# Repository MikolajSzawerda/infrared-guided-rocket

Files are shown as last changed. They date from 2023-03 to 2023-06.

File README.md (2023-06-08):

Mikołaj Szawerda <br/>
Dawid Kaszyński

# Projekt SKPS - Termiczny układ naprowadzania rakiety

## Założenia projektu

Projekt ma za zadanie symulować termiczny układ naprowadzania rakiety poprzez zczytywanie danych z kamery termowizyjnej i odpowiednie sterowanie dwoma serwomechanizmami w taki sposób, żeby nakierowywać w najcieplsze miejsce w obrazie. Ponadto system powinien wizualizować w czasie rzeczywistym przetwarzany obraz oraz wyświetlać wybrany cel.

## Wykonanie - zdjęcia

### Urządzenie i podłączone serwomechanizmy oraz kamera

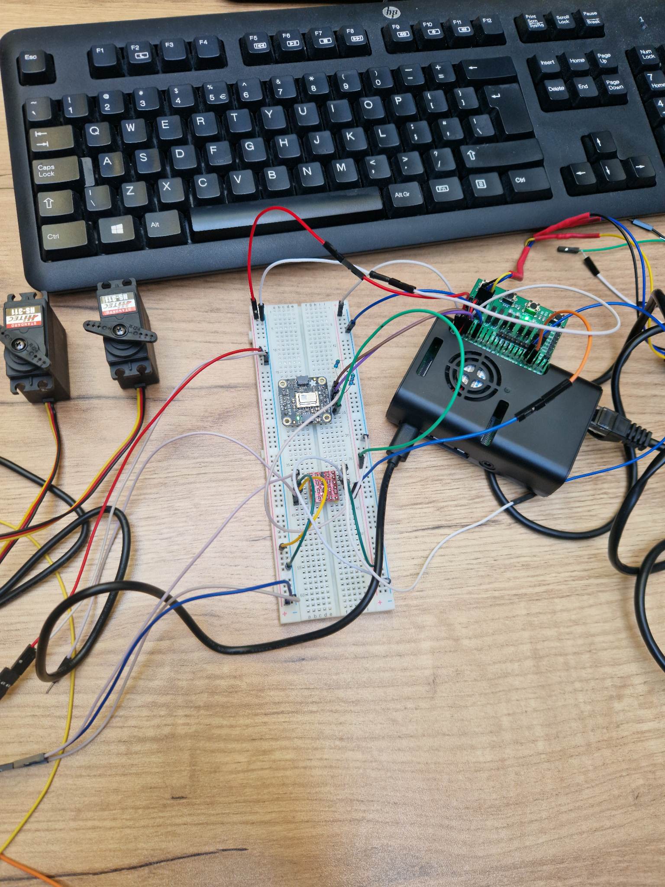
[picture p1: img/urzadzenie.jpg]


### Urządzenie wraz z widoczną wizualizacją i najcieplejszym punktem (czarna kropka na mapie ciepła)

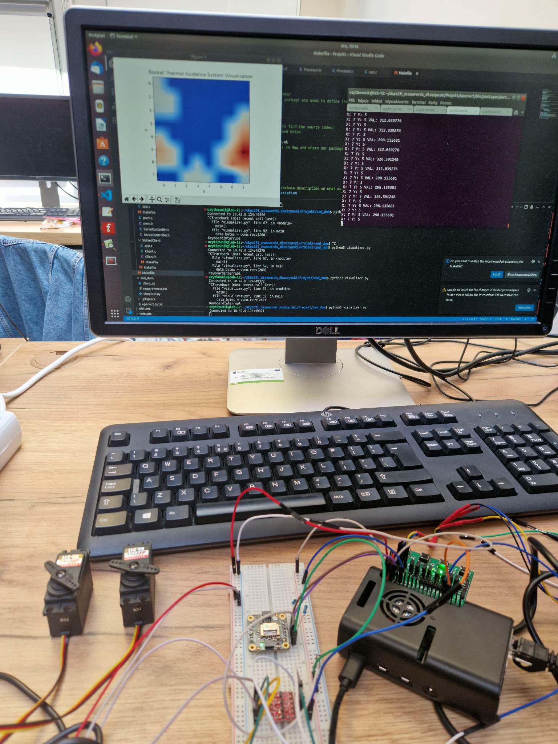
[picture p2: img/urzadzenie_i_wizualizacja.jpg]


## Wykonanie - płytka

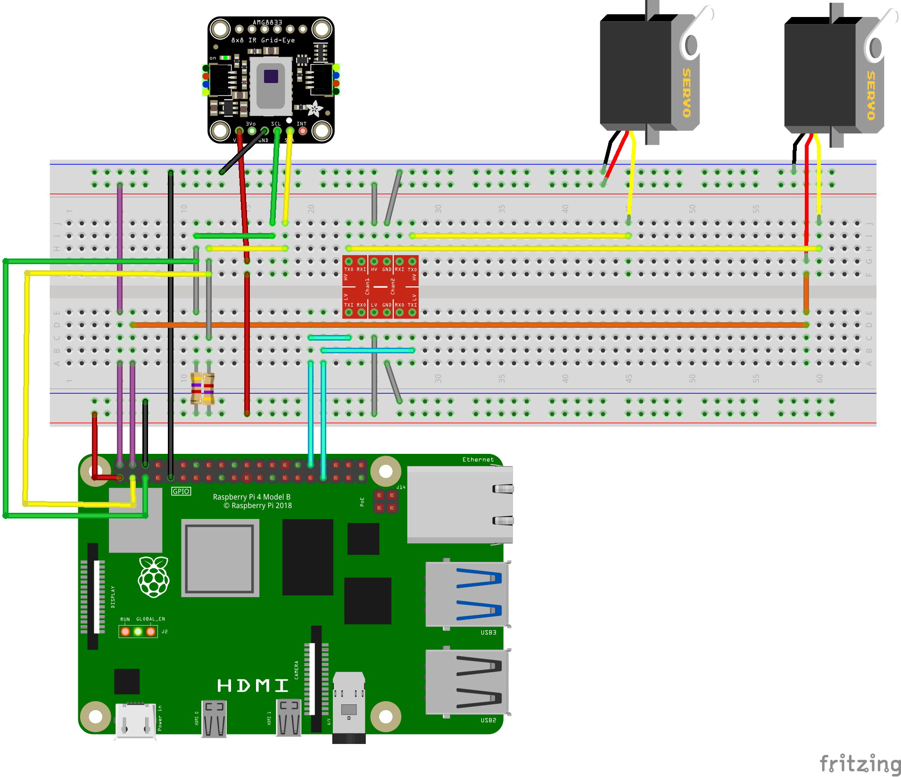
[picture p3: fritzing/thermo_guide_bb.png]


- kamera z racji komunikacji po I2C jest podłączona wraz z pull up resistorami do lini SCL i SDA
- servomechanizmy z racji wymaganego sterovania 5V są podłączone do RPI poprzez konwerter poziomów logicznych z 3.3V na 5V

## Wizualizacja

Wizualizacja w czasie rzeczywistym została zrealizowana przy pomocy połączenia RPi4 z hostem poprzez socket oraz z użyciem biblioteki matplotlib, która umożliwa wyświetlenie mapy ciepła 8x8 z włączoną interpolacją i odpowiednią kolorystyką.

Dane wysyłąne z płytki poprzez sockety to bufor 65-bajtowy, z czego pierwsze 64 bajty to dane odczytane z kamery termowizyjnej, a ostatni bajt to połozenie najciepleszego punktu, który w wizualizacji jest reprezentowany przez czarną kropkę.

## Algorytm wyszukiwania najcieplejszego punktu

Pierwszym, najprostszym pomysłem na realizację algorytmu wyszukiwania najcieplejszego punktu było zwykłe wyszukiwanie najcieplszego pixela odczytanego z kamery. Dawało to jednak złe rezultaty, ze względu na bardzo dużą oscylację odczytów i brak możliwości skupienia się na konkretnym punkcie, gdy w zasięgu kamery pojawiały się inne o zbliżonej temperaturze.

Z tego względu zdecydowaliśmy się na rozwiązanie polęgające na iteracji po całym obrazie 8x8 macierzą 3x3 i uwzględnianie średniej ważonej temperatury z całego mniejszego obszaru. Ponadto, parametrem algorytmu jest najcieplejszy punkt z poprzedniego odczytu, który powoduje, że w przypadku występowania dwóch równie ciepłych punktów w obrazie z kamery, algorytm preferuje wybór tego, który był wybrany poprzednio - umożliwia to skupienie się na konkretnym punkcie i redukuje oscylację. Co iterację wartość poprzedniego najcieplejszego punktu jest delikatnie zmniejszana poprzez mnożenie przez pewien współczynnik, aby wykluczyć zapamiętywanie punktów, które nie istnieją już w nowym odczycie z kamery.

Dodatkowym usprawnieniem jest także progowanie - odcianie temperatury do przedziału [a, b], które powoduje, że obraz jest mniej rozmyty i można lepiej rozróżnić ciepłe obszary.

## Aplikacja na RPI

Aplikacja uruchomiona na RPI została podzielona na moduły, znajdujące się w folderze `thermo_guide/src`

### SocketClient
- implementacja klienta komunikującego się po TCP socketami. Klient umożliwia przesłanie przetwarzanych przez niego danych(obrazu z kamery) i końcowego rezultatu algorytmu - piksela na który zostają nastawione serwa(indeks w buforze z obrazem)
- w folderze z kodem znajduje się również aplikacja testująca samego klienta - generuje sztuczny obraz(orbitujący punkt) wraz z losowym szumem i przesyła go po socketcie

### ServoController
- moduł z funkcjami umożliwiającymi sterowanie serwami
- funkcje korzystają z fragmentu biblioteki `C-periphery` w celu wysterowania odpowiedniego sygnału PWM.
- funkcja `init_servo` rozpoczyna komunikację programu z chipem pwm i ustawia częstotliwość pracy PWM
- ponieważ nie posiadaliśmy informacji o typie serva przed laboratoriami przygotowaliśmy funkcję sterujące servem w trybie ciągłym i wychyleniowym
- `set_servo_rot_direction` ustawia wypełnienie serva, decydując o jego wychyleniu
- `step_set_servo_pixel` mapuje wymagane wychylenie do wypełnienia z przedziału `[MIN_ANGLE, MAX_ANGLE]`
- folder zawiera również aplikację testową do zbadania minimalnego i maksymalnego wypełnienia dającego zmianę wychylynie

### ImageProcessor
- moduł z implementacją algorytmu znajdowania najcieplejszego punktu
- folder zawiera również aplikację do testowania funkcjonalności

### Camera
- moduł do pobierania danych z kamery wykorzystując I2C
- pakiet jest fuzją oficjalnej biblioteki do kamery w C i części biblioteki `C-periphery` do obsługi protokołu I2C.
- folder zawiera aplikację testującą odczytywane dane

### App
- główna aplikacja wykorzystująca zaimplementowane funkcjonalności
- przepływ aplikacji:
    - inicjacja połączenia z serverm na hoscie
    - inicjacja urządzenia I2C i sygnału PWM dla serv
    - w pętli:
        - odczyt z kamery
        - przetworzenie obrazu i odebranie najcieplejszego punkty
        - wysterowanie serv i wysyłka pakietu do servera
        - odczekanie w celu równomiernego próbkowania obrazu

### Pozostałe
- w celu ułatwienia i przyspieszenia pracy z OpenWRT w folderze `scripts/` znajdują shell'owe skrypty

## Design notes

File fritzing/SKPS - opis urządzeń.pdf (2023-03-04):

# Obsługa interfejsów komunikacyjnych na RPi

Dokument przygotowany dla przedmiotu SKPS Autor: Dawid Seredyński

i2c

Należy podłączyć do linii SDA i SCL rezystory o wartości około 4,7kΩ (pull-up).

Trzeba dodać do config.txt na partycji boot:
dtoverlay=i2c1

i2c1 (przez GPIO 2 i 3) jest wyprowadzone na adapterze na dedykowanym złączu.

W OpenWRT należy doinstalować:
kmod-i2c-bcm2835

Podłączone urządzenie można wykryć za pomocą polecenia: i2cdetect -y 1

## 1-wire

Włączenie 1-wire interface w RPi (przez dtoverlay) jest opisane m.in. na stronie: https://www.raspberrypi-spy.co.uk/2018/02/enable-1-wire-interface-raspberry-pi (uwaga: dla urządzenia DHT11, interfejs włącza się w inny sposób)

# Opis wybranych urządzeń

## VL53L0 - laserowy czujnik odległości (time of flight)

Interfejs: i2c
Adres: 0x29
Możliwości: precyzyjny pomiar odległości w zakresie 2m.

Dokumentacja jest dostępna pod adresem: https://download.kamami.pl/p570404-VL53L0X%20Datasheet.pdf

Urządzenie wymaga użycia bardzo złożonego API.
Uruchomienie na RPi wymaga skorzystania z oryginalnego API od ST, które jest dostępne pod adresem:
https://www.st.com/en/embedded-software/stsw-img005.html

Należy ściągnąć STSW-IMG005. API jest bezpłatne, ale wymagane jest podanie i potwierdzenie adresu e-mail.

Następnie można skorzystać z biblioteki dla RPi: https://github.com/cassou/VL53L0X_rasp

Plików źródłowych w API i w bibliotece nie trzeba zmieniać, a jedyna trudność polega na stworzeniu pakietu dla OpenWRT, w którym będą pliki źródłowe z API i biblioteki.

## LCD-02351 (2x16 znaków) + konwerter i2c

Interfejs: i2c
Możliwości: wyświetlanie tekstu w dwóch liniach po 16 znaków.

Konwerter i2c na bazie PCF8574.

## DFR0316 - 18-bitowy, 4-kanałowy konwerter analogowo -cyfrowy

Interfejs: i2c
Możliwości: konwersja analogowego sygnały (poziom napięcia) na cyfrową wartość 18-bitową, na 4 kanałach.

Moduł na bazie układu MCP3424 (dokumentacja jest na Moodle).

## AMG8833 - kamera termowizyjna 8x8

Interfejs: i2c
Adres: 0x69
Możliwości: Uzyskanie obrazu termowizyjnego 8x8 dla zakresu temperatur 0-80 st. C.

Dokumentacja jest dostępna na stronie kursu na Moodle.

Prosta obsługa. Można skorzystać z fragmentów kodu biblioteki dla Arduino: https://github.com/adafruit/Adafruit_AMG88xx

## DHT11 - czujnik temperatury i wilgotności

Interfejs: 1-wire
Możliwości: pomiar temperatury i wilgotności

Można uruchomić zgodnie z opisem dostępnym pod adresem: https://krystiankozak.pl/index.php/openwrt-gpio
Sterownik na RPi dla DHT11 nie działa jednak najlepiej, ale możliwe jest dokonanie odczytów.

## Jednostka inercyjna

Interfejs: i2c, SPI
Możliwości: pomiar przyspieszenia w 3 osiach, prędkości obrotowej w 3 osiach. Dodatkowo, w MPU-9250 jest także pomiar pola magnetycznego w 3 osiach.

Dostępne są dwa rodzaje jednostki inercyjnej:
- Grove - IMU 9DOF v2.0 - 3-osiowy akcelerometr, żyroskop i magnetometr I2C/SPI z układem MPU-9250. Datasheet i mapa rejestrów są udostępnione na Moodle.
- MPU-6050 3-osiowy akcelerometr i żyroskop I2C - moduł DFRobot. Datasheet i mapa rejestrów są udostępnione na Moodle.

## Moduł radiowy nRF24L01+ 2,4GHz - transceiver THT

Interfejs: SPI
Możliwości: Posiada wbudowaną antenę oraz sprzętowe kolejki FIFO. Maks. zasięg do 100m

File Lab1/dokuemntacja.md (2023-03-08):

# Lab1
## Dawid Kaszyński Mikołaj Szawerda

### Uruchomienie RPi

Do terminala UART podłączyliśmy się wykonując komendę `tio /dev/ttyUSB01`

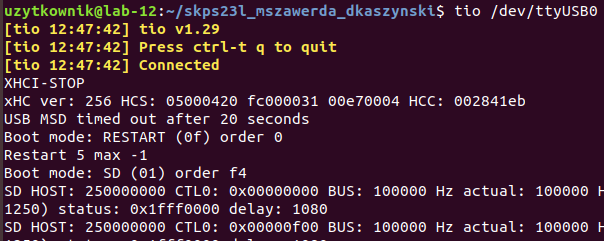
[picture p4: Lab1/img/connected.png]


Po uruchomieniu zasialania na RPi został uruchomiony system ratunkowy, zalogowaliśmy się na niego z loginem root, a następnie wykonaliśmy polecenie `udhcp`, by został przyznany adres IP

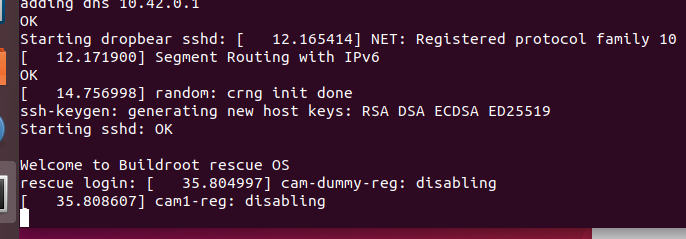
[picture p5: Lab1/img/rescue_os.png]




Sprawdzenie utworzenia podsieci między hostem a RPi.

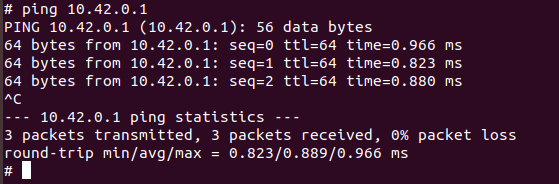
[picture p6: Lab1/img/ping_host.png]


### Kopiowanie plików

#### Test

W celu przetestowania przesyłania plików utworzyliśmy serwer http przy pomocy polecenia `python3 -m http.server`, następnie na hoscie utworzyliśmy plik testowy `foobar`, umieściliśmy go na serwerze, i na RPi pobraliśmy go korzystając z komendy `wget http://10.42.0.1:8000/foobar`



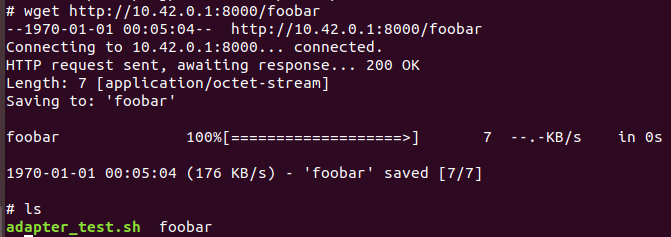
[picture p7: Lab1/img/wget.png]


### Kompilacja obrazu Linuxa

- po rozpakowaniu archiwum z Buildroota, wykorzystaliśmy predefiniowaną konfigurację domyślną dla RBi4 oraz uruchomiliśmy menu konfiguracji
```
make raspberrypi464defconfig
make menuconfig
```

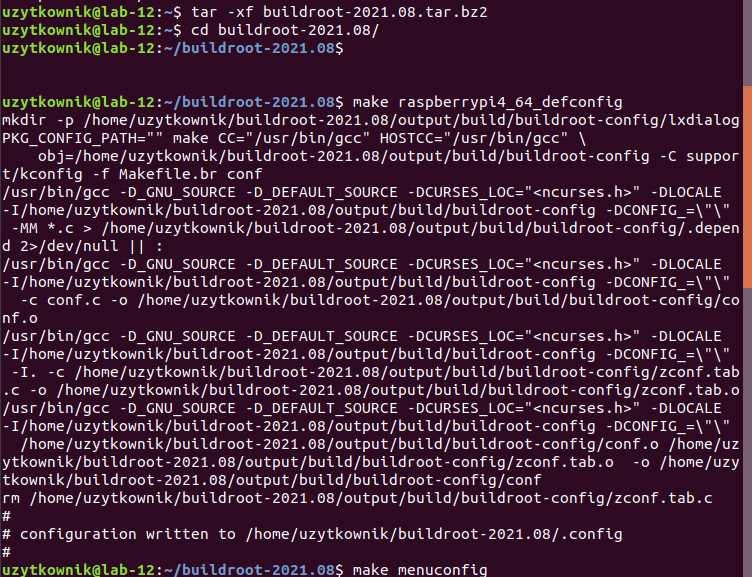
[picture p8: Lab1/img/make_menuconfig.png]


#### Wersja initramfs

Kroki:
- w meny wybranie `Toolchain --> Toolchain type: External toolchain`
- w filesystem images: zaznaczenie cpio, opcji initramfs i wyłączenie ext2/3/4, włączenie kompresji obrazu: gzip
- zapis ustawień w `.config` i urochomienie kompilacji `make`
- zamontowaliśmy partycję 1 w /mnt przy pomocy `mount /dev/mmcblk0p1 /mnt`
- skompilowany obraz `Image` pod nazwą `kernel8.img`, linię poleceń `cmdline.txt` z katologu `rpi-firmware`  i drzewo urządzeń `bcm2711-rpi-4-b.dtb` pobraliśmy z poziomu systemu ratunkwoego do katologu `/user`
- zrestartowaliśmy RBi4 `reboot` z wciśniętym przyciskiem `sw4`

#### Wersja bez initramfs

Kroki:
- usuneliśmy poprzedni obraz systemy `make linux-dirclean`
- z poprzedniej konifguracji pozostawiliśmy włączony External toolchain, oraz kompresję obrazu w Kernel
- w filesystem images: wyłączyliśmy initramfs, włączyliśmy ext2/3/4
- `make`



- następnie po uruchomieniu systemu dodaliśmy plik `test` i wykonaliśmy `reboot` systemu, po uruchomieniu plik dalej był w systemie plików

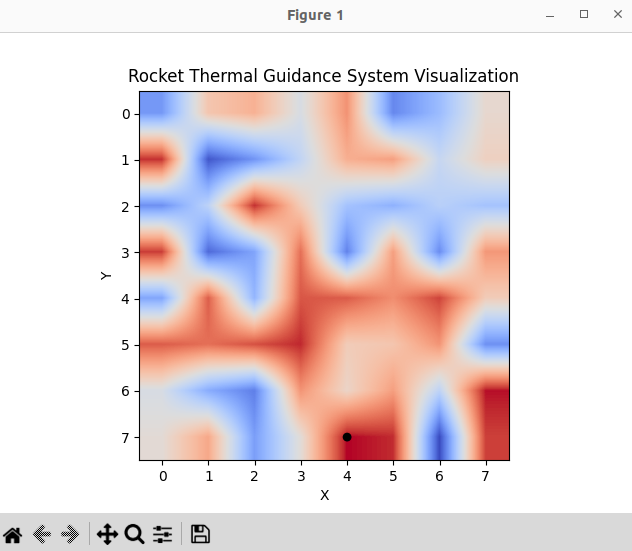
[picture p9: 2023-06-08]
img/visualization.png

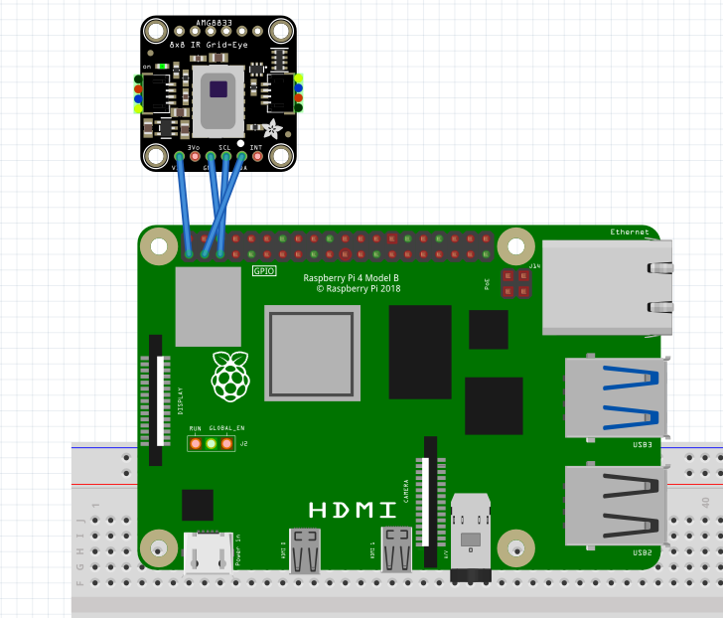
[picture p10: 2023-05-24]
schemat_termo.png

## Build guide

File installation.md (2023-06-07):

## Install OpenWRT

```shell
wget -O openwrt.tar.xz https://downloads.openwrt.org/releases/21.02.1/targets/bcm27xx/bcm2711/openwrt-sdk-21.02.1-bcm27xx-bcm2711_gcc-8.4.0_musl.Linux-x86_64.tar.xz
tar -xf openwrt.tar.xz
```

## Make link

```shell
ln -s ../../../thermo_guide thermo_guide 
```

## Preconfig openwrt

### Feeds.conf.default
```
src-link thermo_guide package/thermo_guide/src
```

### Config

```shell
scripts/feeds update -a
scripts/feeds install -p thermo_guide -a 
make menuconfig
```

Global Build Settings wyłaczyć opcje:
Select all target specific packages by default
Select all kernel module packages by default
Select all userspace packages by default
Cryptographically sign package lists

Advanced configuration options wskazane jest wyłaczenie opcji
Automatic removal of build directories

Dodać pakiet w do budowania

### Budowanie

```shell
make package/thermo_guide/compile -j4
```

```shell
make package/thermo_guide/compile -j1 V=s
```

## Na openwrt

```shell
/etc/init.d/firewall stop
```

### config.txt
```
dtoverlay=pwm-2chan,pin=12,func=4,pin2=13,func2=4
dtoverlay=i2c1
```

### Install

```shell
kmod-i2c-bcm2835
kmod-pwm-bcm2835
```

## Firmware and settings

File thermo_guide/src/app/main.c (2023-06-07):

#include <stdio.h>
#include <unistd.h>
#include <stdlib.h>
#include <string.h>
#include "../Camera/Camera.h"
#include "../SocketClient/Client.h"
#include "../ServoController/ServoController.h"
#include "../ImageProcessor/Processor.h"
#define BUFFER_SIZE 64
#define SERVER_IP "10.42.0.1"
#define SERVER_PORT 6969

double t = 0;

void print_buffer(float* buffer);

int main(){
    int sockfd = init_server_connection(SERVER_IP, SERVER_PORT);
    struct client_package clientPackage;
    struct HotSpot hotSpot={3,3, -1};
    memset(clientPackage.buffer, 0, sizeof(float)*BUFFER_SIZE);
    i2c_t* i2c_dev = begin();
    struct servo servoX = init_servo(1);
    struct servo servoY = init_servo(0);
    for(;;){
        //generate_fake_circle(clientPackage.buffer, t);
        readPixels(i2c_dev, clientPackage.buffer, BUFFER_SIZE);
        // hotSpot = getHottestSpot(clientPackage.buffer);
        struct HotSpot currentHotSpot = getHottestSpot2(clientPackage.buffer, &hotSpot);
        clientPackage.hottestSpot = flattenHotSpot(&currentHotSpot);

        if(send_packet(sockfd, &clientPackage) < 0){
            perror("Error sending packet\n");
            exit(1);
        } else {
            printf("X: %d Y: %d\n", hotSpot.x, hotSpot.y);
        }
        step_set_servo_pixel(&servoX, hotSpot.y);
        step_set_servo_pixel(&servoY, hotSpot.x);

        // t = fmod(t+0.3, 2*M_PI);
        oldHotSpotDecay(&currentHotSpot);
        hotSpot = currentHotSpot;
        usleep(100000);

    }
    close(sockfd);

    return 0;
}


void print_buffer(float* buffer){
    for(int i=0;i<8;i++){
        for(int j=0;j<8;j++){
            printf("%f ", buffer[8*i+j]);
        }
        printf("\n");
    }
}

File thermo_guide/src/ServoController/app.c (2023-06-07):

#include "ServoController.h"
#include <unistd.h>

int main(){
    struct servo s = init_servo(1);
//    rotate_by_angle(&s, 90.0);
//    sleep(2);
//    rotate_by_angle(&s, -90.0);
//    set_servo_rot_direction(&s, IDLE);
        for(int i=0;i<100;i++){
            set_servo_rot_direction(&s, (double) i/100.0);
            printf("DIR: %f", (double)i/100.0);
            sleep(2);
        }
//    for(int i=0;i<=180;i+=10){
//        step_set_servo_angle(&s, (double)i);
//        printf("ANGLE: %d\n", i);
//        sleep(2);
//    }
    destroy_servo(&s);
}

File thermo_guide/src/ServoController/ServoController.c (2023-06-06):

#include "ServoController.h"

struct servo init_servo(unsigned int channel){
    pwm_t *pwm;
    pwm = pwm_new();
    struct servo s = {pwm, IDLE, 0.0f, MIDDLE_POINT};
    if (pwm_open(pwm, 0, channel) < 0) {
        fprintf(stderr, "pwm_open(): %s\n", pwm_errmsg(pwm));
    }

    if (pwm_set_frequency(pwm, SERVO_FREQ) < 0) {
        fprintf(stderr, "pwm_set_frequency(): %s\n", pwm_errmsg(pwm));
    }

    if (pwm_set_duty_cycle(pwm, IDLE) < 0) {
        fprintf(stderr, "pwm_set_duty_cycle(): %s\n", pwm_errmsg(pwm));
    }

    if (pwm_enable(pwm) < 0) {
        fprintf(stderr, "pwm_enable(): %s\n", pwm_errmsg(pwm));
    }
    return s;
}

int set_servo_rot_direction(struct servo* s, double direction){
    if (pwm_set_duty_cycle(s->handle, direction) < 0) {
        fprintf(stderr, "pwm_set_duty_cycle(): %s\n", pwm_errmsg(s->handle));
        return -1;
    }
    return 0;
}

int rotate_by_angle(struct servo* s, double angle){
    unsigned int time = floor(fabs((angle/OMEGA)*1e6));
    printf("TIME: %d ", time);
    if(angle>0){
        set_servo_rot_direction(s, RIGHT);
        printf("RIGHT\n");
    } else {
        set_servo_rot_direction(s, LEFT);
        printf("LEFT\n");
    }
    usleep(time);
    set_servo_rot_direction(s, IDLE);
    return 0;
}
int servo_to_point(struct servo* s, double point){
    return 0;
}
void destroy_servo(struct servo* s){
//    pwm_close(s->handle);
    pwm_free(s->handle);
}

int step_set_servo_angle(struct servo* s, double angle){
    double pwm_duty = (angle/180.0) * (MAX_SERVO-MIN_SERVO) + MIN_SERVO;
    return set_servo_rot_direction(s, pwm_duty);
}

int step_set_servo_pixel(struct servo* s, int pixel){
    double pwm_duty = ((7.0-pixel)/7.0) * (MAX_SERVO_PX-MIN_SERVO_PX) + MIN_SERVO_PX;
    return set_servo_rot_direction(s, pwm_duty);
}

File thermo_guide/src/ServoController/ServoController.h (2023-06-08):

#ifndef PROJEKT_SERVOCONTROLLER_H
#define PROJEKT_SERVOCONTROLLER_H

#define LEFT 0.035
#define RIGHT 0.10
#define IDLE 0.0
#define SERVO_FREQ 50.0
#define OMEGA 1600
#define MIN_SERVO 0.03
#define MAX_SERVO 0.12
#define MIN_SERVO_PX 0.04
#define MAX_SERVO_PX 0.11

#define MIN_POINT 0.0
#define MAX_POINT 7.0
#define MIDDLE_POINT (MIN_POINT+MAX_POINT)/2.0

#include "pwm.h"
#include <stdio.h>
#include <unistd.h>
#include <math.h>

struct servo{
    pwm_t* handle;
    double direction;
    double current_angle;
    double indicated_point;
};

struct servo_controller {
    struct servo horizontal;
    struct servo vertical;
};

struct servo init_servo(unsigned int channel);
int set_servo_rot_direction(struct servo* s, double direction);
int rotate_by_angle(struct servo* s, double angle);
int servo_to_point(struct servo* s, double point);
void destroy_servo(struct servo* s);

int step_set_servo_angle(struct servo* s, double angle);
int step_set_servo_pixel(struct servo* s, int pixel);

#endif //PROJEKT_SERVOCONTROLLER_H

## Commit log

2023-05-24 added wrtie to i2c
2023-06-03 added socket client module
2023-06-03 Added basic servo controller
2023-06-06 Added step servo handler
2023-06-06 Added two servos
2023-06-06 finished whole flow
2023-06-06 Added breadboard
    [thermo_guide.fzz]
2023-06-06 Add getHottestSpot2 algorithm & got spot via socket sending
2023-06-07 test for servo
2023-06-11 Better project structure
    [thermo_guide.fzz]
